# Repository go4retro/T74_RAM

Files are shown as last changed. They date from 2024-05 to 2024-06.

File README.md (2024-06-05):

# TI74 Battery Backed RAM Cartridge

## Introduction

Reproduction of the Texas Instruments TI-74 Battery Backed RAM Cartridge.  The implementation is based on material from [TEXAS TI-74 BASICALC &amp; 8K RAM Cartridge teardown](https://www.hpmuseum.org/forum/thread-7146.html). The discussion on creating this cartridge is at [TI-74 RAM Cartridges - Tomy Tutor, CC40, 99/2, 99/8, Cortex, 990 mini - AtariAge Forums](https://forums.atariage.com/topic/364366-ti-74-ram-cartridges/)

## Requirements

- TI-74

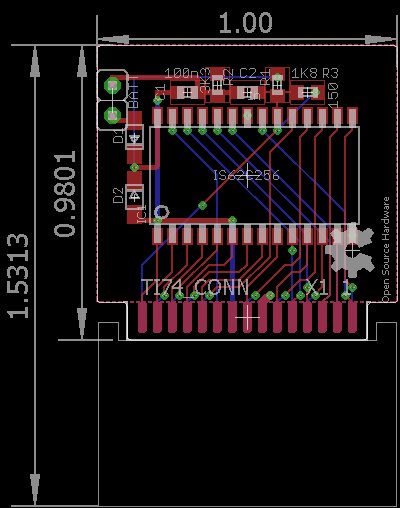
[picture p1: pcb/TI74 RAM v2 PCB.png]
TI-74 RAM Cart PCB


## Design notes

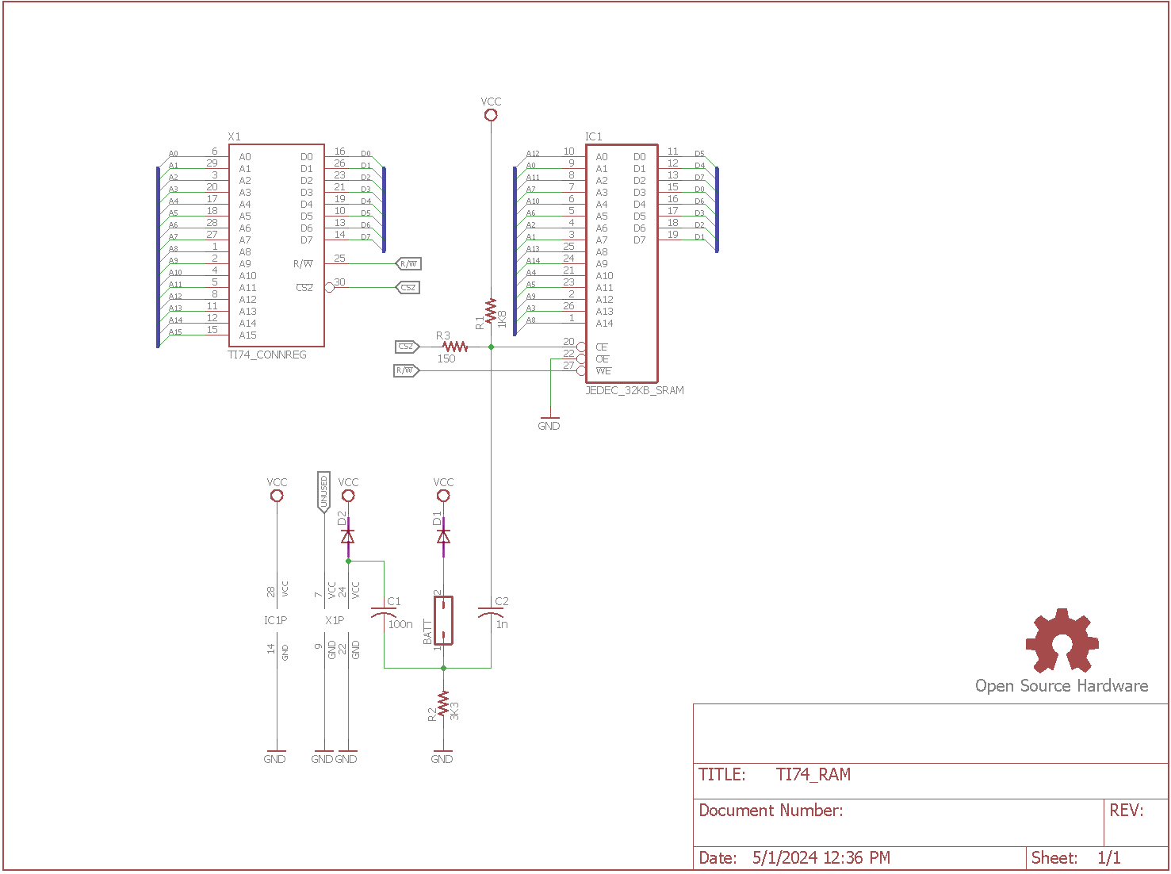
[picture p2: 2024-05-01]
pcb/TI74 RAM Schematic.png

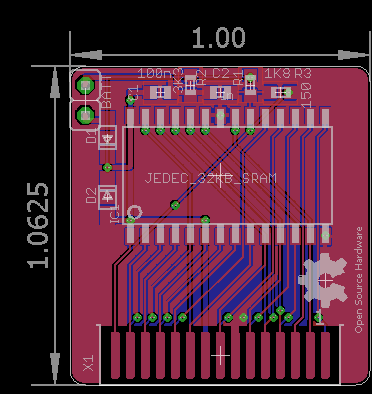
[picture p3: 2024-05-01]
pcb/TI74 RAM PCB.png

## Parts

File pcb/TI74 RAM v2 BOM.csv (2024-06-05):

DigiKey Part # | Manufacturer Part Number | Description | Quantity
706-1310-1-ND | IS62C256AL-45ULI-TR | IC SRAM 256KBIT PARALLEL 28SOP | 1
CUS520H3FCT-ND | CUS520,H3F | DIODE SCHOTTKY 30V 200MA USC | 2
1292-WR06X151JTLCT-ND | WR06X151 JTL | RES 150 OHM 5% 1/10W 0603 | 1
118-CR0603-JW-182ELFCT-ND | CR0603-JW-182ELF | RES SMD 1.8K OHM 5% 1/10W 0603 | 1
4713-GMC10X7R104K25NTCT-ND | GMC10X7R104K25NT | CAP0603 X7R .1UF 10% 25V | 1
1292-1381-1-ND | 0603B102M500CT | CAP CER 1000PF 50V X7R 0603 | 1
151-302-030-221-201-ND | 302-030-221-201 | 302 SERIES (.05" (1.27MM) CONTAC | 1

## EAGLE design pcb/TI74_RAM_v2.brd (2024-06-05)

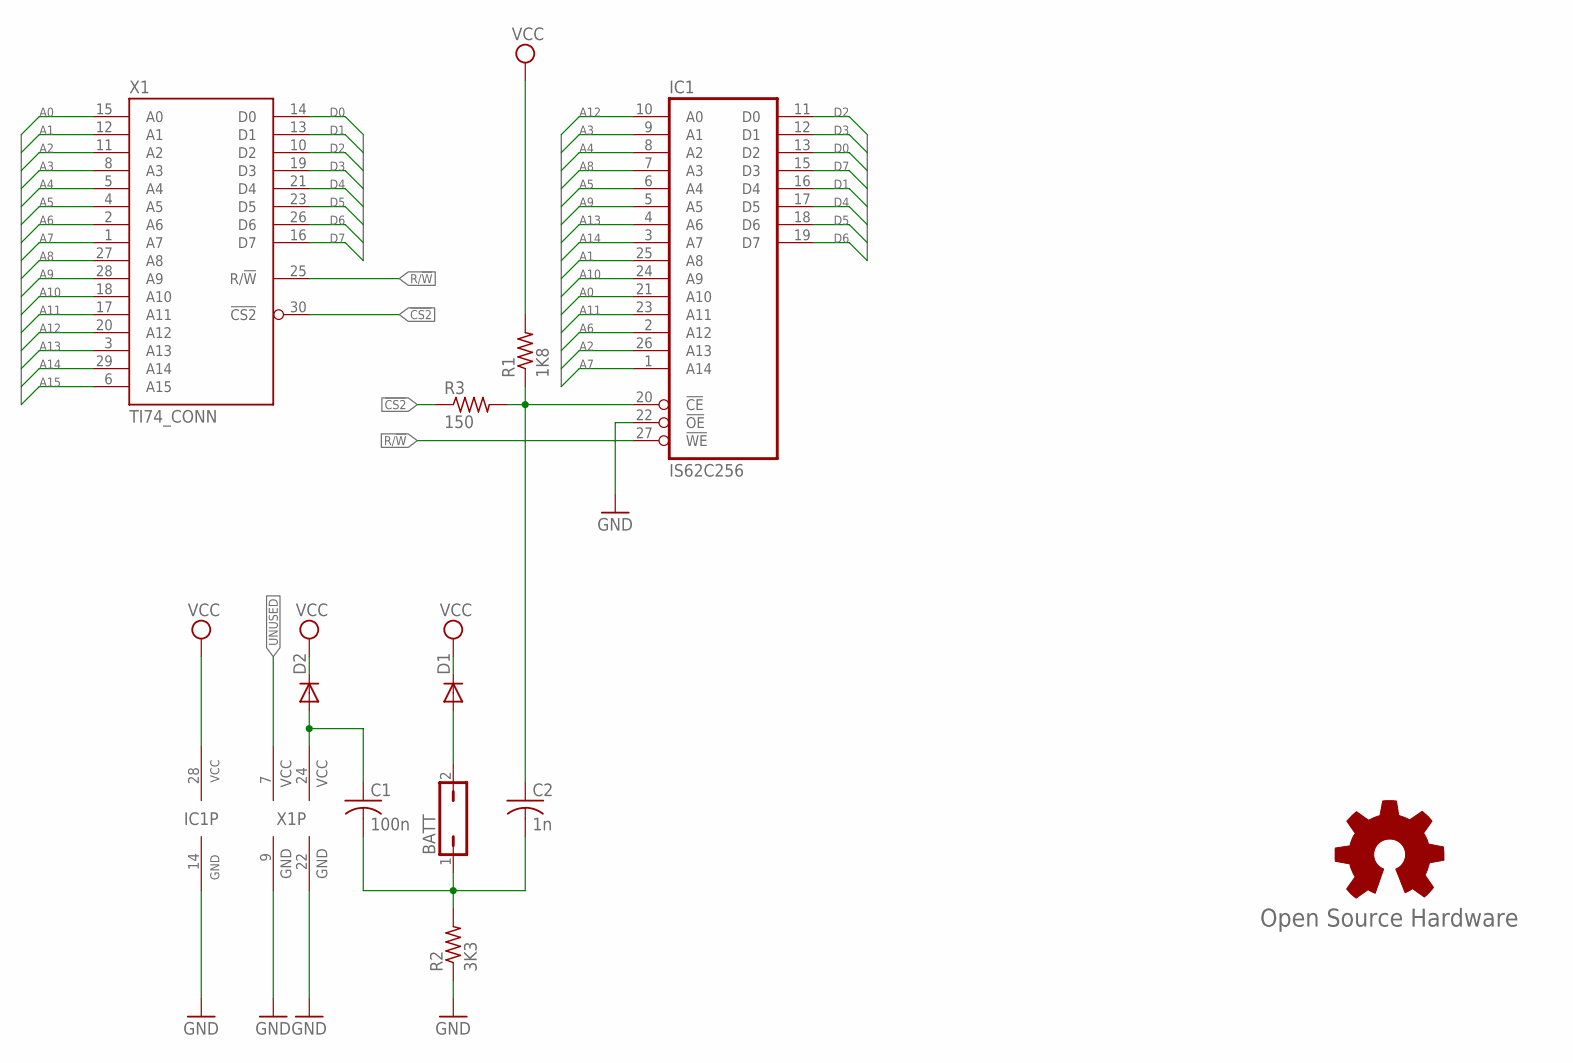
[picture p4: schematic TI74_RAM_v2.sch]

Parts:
BATT: JP1Q; JP1
C1: 100n; C0603
C2: 1n; C0603
D1, D2: DIODE-SOD323-W; SOD323-W
GOLD_ORB_SM1: Open Source Hardware; OSHW_5MM
IC1: IS62C256; SO28L
R1: 1K8; R0603
R2: 3K3; R0603
R3: 150; R0603
X1: TI74_CONN; MA050-15-2SHORT

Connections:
!CS2: R3.1, X1.30 (!CS2)
A0: IC1.21 (A10), X1.15 (A0)
A1: IC1.25 (A8), X1.12 (A1)
A2: IC1.26 (A13), X1.11 (A2)
A3: IC1.9 (A1), X1.8 (A3)
A4: IC1.8 (A2), X1.5 (A4)
A5: IC1.6 (A4), X1.4 (A5)
A6: IC1.2 (A12), X1.2 (A6)
A7: IC1.1 (A14), X1.1 (A7)
A8: IC1.7 (A3), X1.27 (A8)
A9: IC1.5 (A5), X1.28 (A9)
A10: IC1.24 (A9), X1.18 (A10)
A11: IC1.23 (A11), X1.17 (A11)
A12: IC1.10 (A0), X1.20 (A12)
A13: IC1.4 (A6), X1.3 (A13)
A14: IC1.3 (A7), X1.29 (A14)
A15: X1.6 (A15)
D0: IC1.13 (D2), X1.14 (D0)
D1: IC1.16 (D4), X1.13 (D1)
D2: IC1.11 (D0), X1.10 (D2)
D3: IC1.12 (D1), X1.19 (D3)
D4: IC1.17 (D5), X1.21 (D4)
D5: IC1.18 (D6), X1.23 (D5)
D6: IC1.19 (D7), X1.26 (D6)
D7: IC1.15 (D3), X1.16 (D7)
GND: IC1.14 (GND), IC1.22 (!OE), R2.1, X1.9 (GND), X1.22 (GND)
unnamed: C2.1, IC1.20 (!CE), R1.1, R3.2
unnamed: C1.1, D2.A, X1.24 (VCC_RAM)
unnamed: BATT.2, D1.A
unnamed: BATT.1, C1.2, C2.2, R2.2
R/!W: IC1.27 (!WE), X1.25 (R/!W)
UNUSED: X1.7 (VCC)
VCC: D1.C, D2.C, IC1.28 (VCC), R1.2

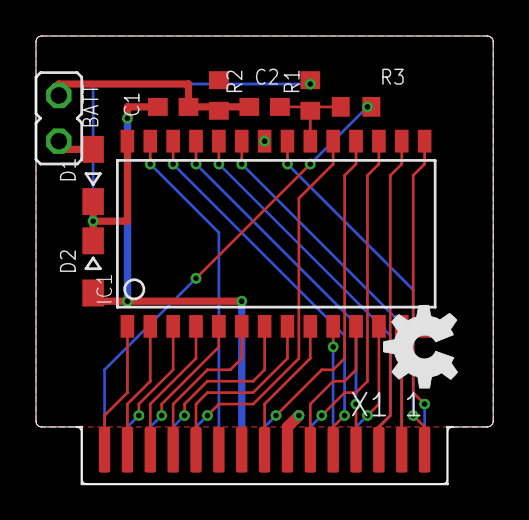
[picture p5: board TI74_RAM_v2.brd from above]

Board: 2 copper layers, 25.4 x 24.9 mm, 11 parts (0 on the bottom side), 31 nets.

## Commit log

2024-04-30 Update PCB Image
2024-05-01 Add in A14 address line
    [TI74_RAM.brd, TI74_RAM.sch]
2024-06-01 Fixed A15->A0 mistake and shortened board (v2)
    [TI74_RAM_v2.brd, TI74_RAM_v2.sch]
2024-06-05 small adjustments
    [TI74 RAM v2 BOM.csv, TI74_RAM_v2.brd]
